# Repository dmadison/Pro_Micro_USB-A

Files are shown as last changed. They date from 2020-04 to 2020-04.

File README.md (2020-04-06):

Pro Micro w/ USB-A
=========

Pro Micro w/ USB-A

The Pro Micro is a micro controller with an ATMega32U4 IC on board.
The USB transceiver is inside the 32U4, adding USB connectivity on-board without external USB interfaces. 
This comes in both a 3.3V and 5V version. 

This repository was forked from [the original SparkFun Pro Micro repository](https://github.com/sparkfun/Pro_Micro). The board has been modified to use [a USB-A](https://en.wikipedia.org/wiki/USB_hardware#Connectors) connector.

For more information, see [the blog post on PartsNotIncluded.com](https://www.partsnotincluded.com/sparkfun-pro-micro-with-usb-a/).

Repository Contents
-------------------
* **/Documentation** - Data sheets (.pdf and .svg)
* **/Firmware** - Arduino example code used in the hookup guide
* **/Hardware** - All Eagle design files (.brd, .sch, .STL)
* **/Production** - Test bed files and production panel files

Documentation
--------------
* **[Hookup Guide](https://learn.sparkfun.com/tutorials/pro-micro--fio-v3-hookup-guide)** - Basic hookup guide for the Pro Micro.
* **[SparkFun Arduino Board Addon](https://github.com/sparkfun/Arduino_Boards/)** - Arduino board addon for Pro Micro.
* **[SparkFun Graphical Datasheets](https://github.com/sparkfun/Graphical_Datasheets)** - Graphical datasheets for various SparkFun products.
* **[USB-A Build Log](https://www.partsnotincluded.com/sparkfun-pro-micro-with-usb-a/)** - Build log for the USB-A version on PartsNotIncluded.com

Product Versions
----------------
* [DEV-12587](https://www.sparkfun.com/products/12587)- 3.3V/8MHz version
* [DEV-12640](https://www.sparkfun.com/products/12640)- 5V/16MHz version

License Information
-------------------
This product is _**open source**_! 

Please review the LICENSE.md file for license information. 

If you have any questions or concerns on licensing, please contact techsupport@sparkfun.com.

Distributed as-is; no warranty is given.

- Your friends at SparkFun.

_<COLLABORATION CREDIT>_

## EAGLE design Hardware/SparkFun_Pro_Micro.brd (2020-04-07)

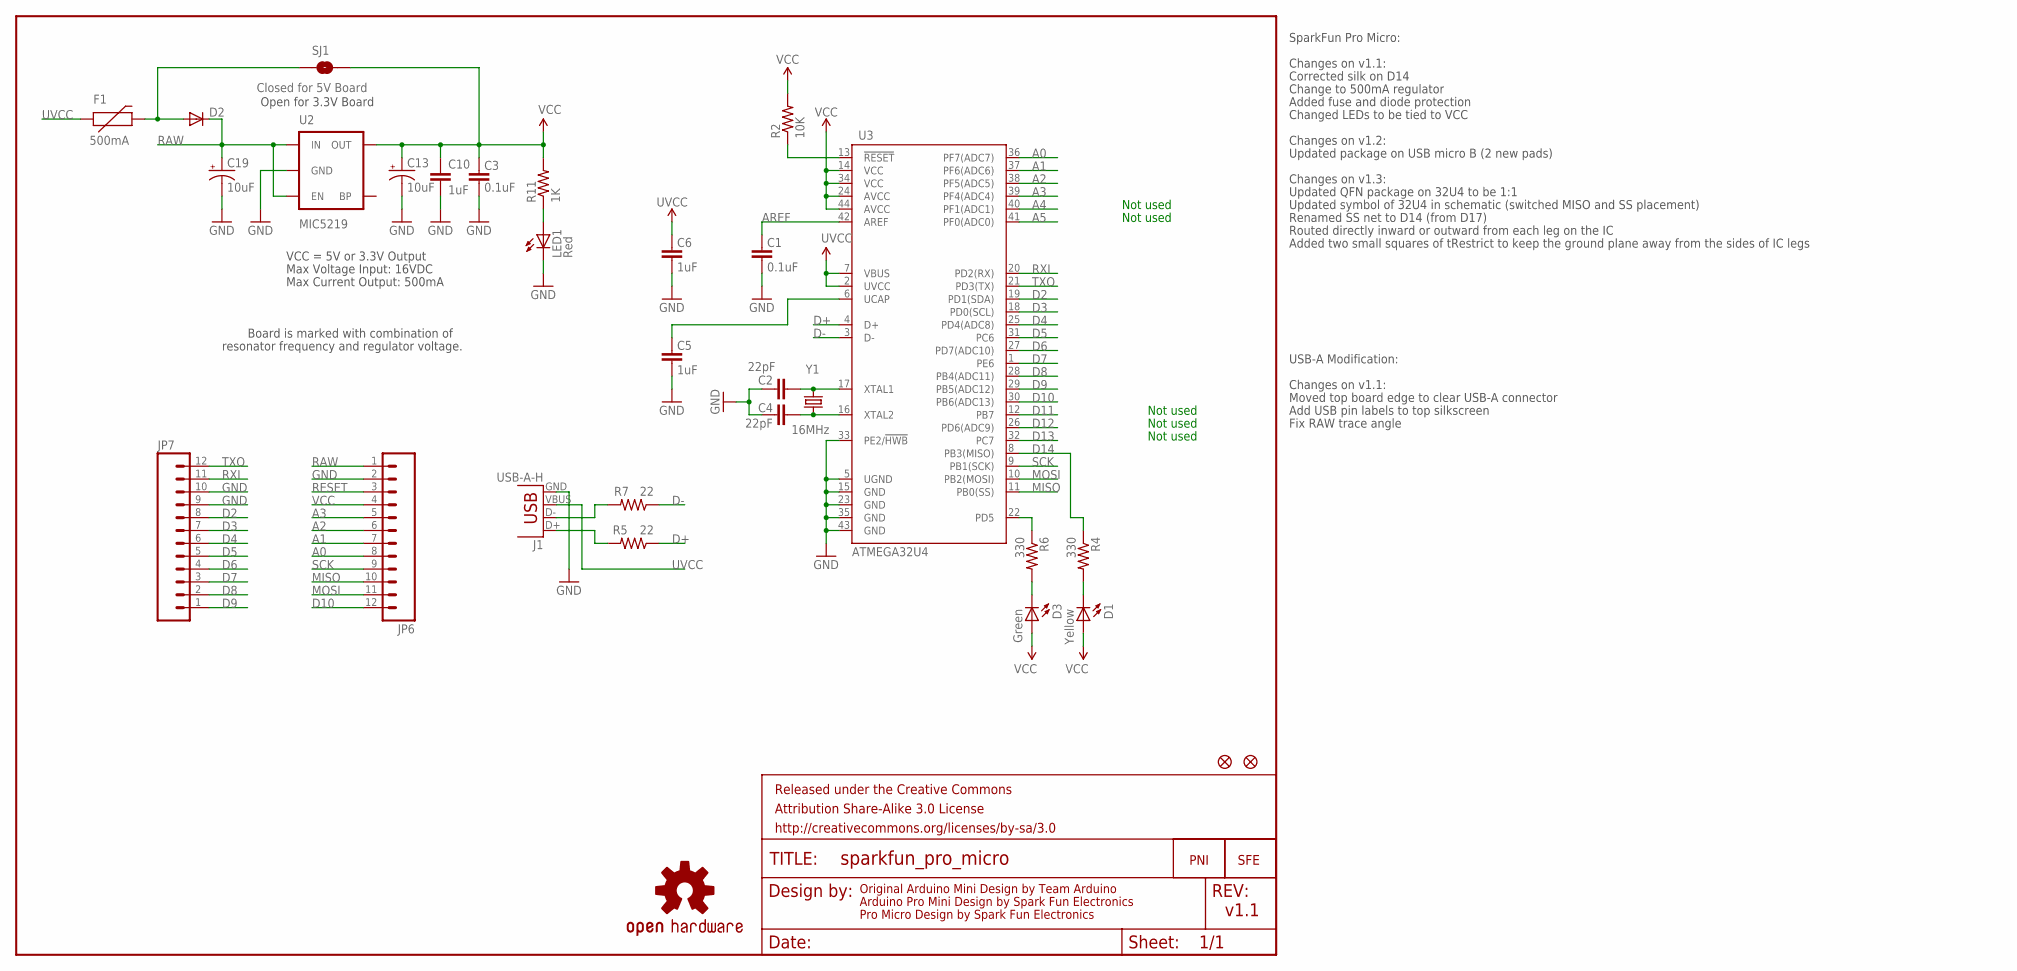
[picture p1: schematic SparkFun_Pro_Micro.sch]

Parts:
C1, C3: 0.1uF; 0603-CAP
C2, C4: 22pF; 0603-CAP
C5, C6, C10: 1uF; 0603-CAP
C13, C19: 10uF; EIA3216
D1: Yellow; LED-0603
D2: DIODESOD; SOD-323
D3: Green; LED-0603
F1: 500mA; PTC-1206
FRAME1: FRAME-LETTER; CREATIVE_COMMONS
J1: USB-A-H
JP1, JP2: FIDUCIALUFIDUCIAL; MICRO-FIDUCIAL
JP6, JP7: M12PTH; 1X12
LED1: Red; LED-0603
R2: 10K; 0603-RES
R4, R6: 330; 0603-RES
R5, R7: 22; 0603-RES
R11: 1K; 0603-RES
SJ1: Closed for 5V Board; SJ_2S
U2: MIC5219; SOT23-5
U3: ATMEGA32U4; QFN-44-NOPAD_1:1-OUTFAKES
U$1: LOGO-SFESK; SFE-LOGO-FLAME
U$2: PNI-PRO-MICRO-SPLIT-LOGO-TEXT
U$3: OSHW-LOGOS; OSHW-LOGO-S
Y1: 16MHz; CRYSTAL-SMD-5X3

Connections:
A0: JP6.8, U3.36 (PF7(ADC7))
A1: JP6.7, U3.37 (PF6(ADC6))
A2: JP6.6, U3.38 (PF5(ADC5))
A3: JP6.5, U3.39 (PF4(ADC4))
A4: U3.40 (PF1(ADC1))
A5: U3.41 (PF0(ADC0))
AREF: C1.2, U3.42 (AREF)
D2: JP7.8, U3.19 (PD1(SDA))
D3: JP7.7, U3.18 (PD0(SCL))
D4: JP7.6, U3.25 (PD4(ADC8))
D5: JP7.5, U3.31 (PC6)
D6: JP7.4, U3.27 (PD7(ADC10))
D7: JP7.3, U3.1 (PE6)
D8: JP7.2, U3.28 (PB4(ADC11))
D9: JP7.1, U3.29 (PB5(ADC12))
D10: JP6.12, U3.30 (PB6(ADC13))
D11: U3.12 (PB7)
D12: U3.26 (PD6(ADC9))
D13: U3.32 (PC7)
D14: R4.1, U3.8 (PB3(MISO))
D+: R5.1, U3.4 (D+)
D-: R7.1, U3.3 (D-)
GND: C1.1, C2.2, C3.1, C4.2, C5.1, C6.1, C10.2, C13.C (-), C19.C (-), J1.GND, JP6.2, JP7.9, JP7.10, LED1.C, U2.2 (GND), U3.5 (UGND), U3.15 (GND), U3.23 (GND), U3.33 (PE2/!HWB), U3.35 (GND), U3.43 (GND)
MISO: JP6.10, U3.11 (PB0(SS))
MOSI: JP6.11, U3.10 (PB2(MOSI))
unnamed: C4.1, U3.16 (XTAL2), Y1.1
unnamed: C2.1, U3.17 (XTAL1), Y1.3 (2)
unnamed: D2.2 (A), F1.2, SJ1.1
unnamed: C5.2, U3.6 (UCAP)
unnamed: D1.C, R4.2
unnamed: J1.D-, R7.2
unnamed: D3.C, R6.2
unnamed: J1.D+, R5.2
unnamed: LED1.A, R11.1
RAW: C19.A (+), D2.1 (C), JP6.1, U2.1 (IN), U2.3 (EN)
RESET: JP6.3, R2.1, U3.13 (!RESET)
RXI: JP7.11, U3.20 (PD2(RX))
SCK: JP6.9, U3.9 (PB1(SCK))
TXLED: R6.1, U3.22 (PD5)
TXO: JP7.12, U3.21 (PD3(TX))
UVCC: C6.2, F1.1, J1.VBUS, U3.2 (UVCC), U3.7 (VBUS)
VCC: C3.2, C10.1, C13.A (+), D1.A, D3.A, JP6.4, R2.2, R11.2, SJ1.2, U2.5 (OUT), U3.14 (VCC), U3.24 (AVCC), U3.34 (VCC), U3.44 (AVCC)

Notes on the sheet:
Original Arduino Mini Design by Team Arduino
Arduino Pro Mini Design by Spark Fun Electronics
Max Voltage Input: 16VDC
Max Current Output: 500mA
Board is marked with combination of
resonator frequency and regulator voltage.
VCC = 5V or 3.3V Output
Not used
Pro Micro Design by Spark Fun Electronics
Changes on v1.1:
Corrected silk on D14
Change to 500mA regulator
Open for 3.3V Board
Added fuse and diode protection
Changed LEDs to be tied to VCC
Changes on v1.2:
Updated package on USB micro B (2 new pads)
Changes on v1.3:
Updated QFN package on 32U4 to be 1:1
Updated symbol of 32U4 in schematic (switched MISO and SS placement)
Renamed SS net to D14 (from D17)
Routed directly inward or outward from each leg on the IC
Added two small squares of tRestrict to keep the ground plane away from the sides of IC legs
v1.1
SparkFun Pro Micro:
Moved top board edge to clear USB-A connector
Add USB pin labels to top silkscreen
Fix RAW trace angle
USB-A Modification:

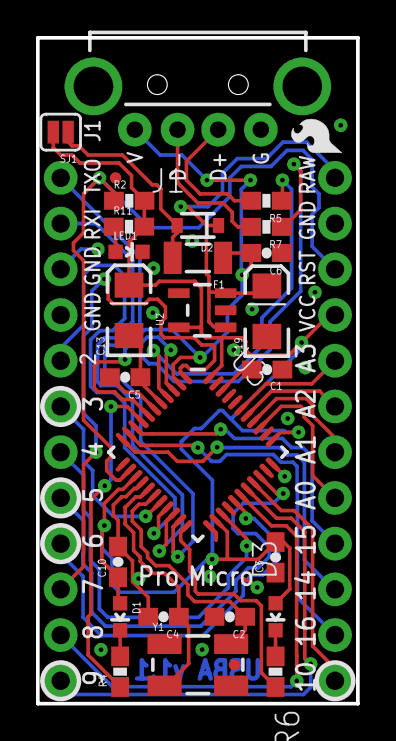
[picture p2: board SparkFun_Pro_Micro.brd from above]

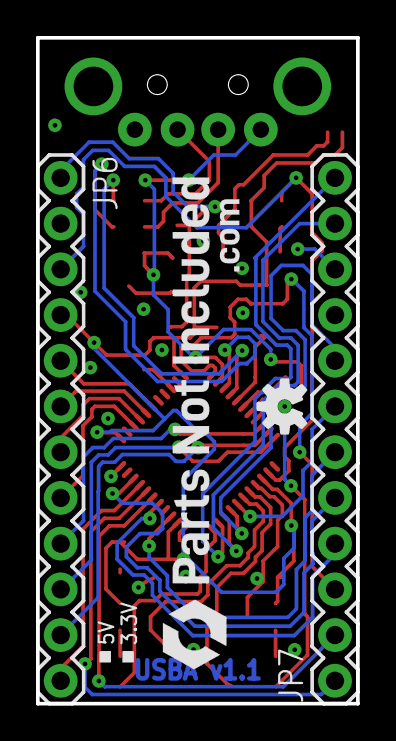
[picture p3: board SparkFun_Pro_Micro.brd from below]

Board: 2 copper layers, 17.8 x 37.0 mm, 33 parts (4 on the bottom side), 37 nets.

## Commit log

2020-02-23 Swap USB-B micro with USB-A male connector
    [SparkFun_Pro_Micro.brd, SparkFun_Pro_Micro.sch]
2020-02-23 Remove SparkFun logo on bottom silkscreen
    This is cleverly hiding in the corner of the schematic as part of the title frame (look for "SFE" on the right).
    [SparkFun_Pro_Micro.brd, SparkFun_Pro_Micro.sch]
2020-02-23 Add PartsNotIncluded logo to bottom silkscreen
    [SparkFun_Pro_Micro.brd, SparkFun_Pro_Micro.sch]
2020-02-23 Update bottom copper version number for USBA
    "v1"!
    [SparkFun_Pro_Micro.brd]
2020-04-04 Move top board edge inwards to clear USB-A jack
    On version 1.0 the jack doesn't *quite* fit without a little sanding. It turns out that the footprint's silkscreen marker for the top of the board clearance area is off by 0.1 mm (3 mm in the footprint, 2.9 mm in the datasheet), and my board edge followed the grid so it was 0.05 mm past even that. This commit pulls the board edge back to properly accomodate the connector.
    Now according to the datasheet the lower edge of the connector is 18.8 mm from the tip, with the mounting tabs 2 mm long. Because the origin of the footprint is the center of these mounting tabs, that makes the origin 17.8 mm offset from the tip. The end of the cutout area is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
    [SparkFun_Pro_Micro.brd]
2020-04-04 Add USB pin labels to top silkscreen
    [SparkFun_Pro_Micro.brd]
2020-04-04 Increase clearance around USB-A trace vias
    [SparkFun_Pro_Micro.brd]
2020-04-04 Fix RAW trace angle
    This was not 45 degrees!
    [SparkFun_Pro_Micro.brd]
2020-04-04 Tweak USB pin silkscreen labels to use "D" prefix
    More clearly distinguishing the data pins from the power and ground (which could also conceivably be confused with '+' and '-')
    [SparkFun_Pro_Micro.brd]
2020-04-04 USBA Version 1.1 on bottom copper
    [SparkFun_Pro_Micro.brd]
2020-04-06 Update version number in schematic (v1.1)
    Using the USB-A version number instead of the Pro Micro number, for internal consistency
    [SparkFun_Pro_Micro.sch]
2020-04-06 Add USB-A version changes to schematic
    [SparkFun_Pro_Micro.sch]
2020-04-07 Center version number on bottom copper
    [SparkFun_Pro_Micro.brd]

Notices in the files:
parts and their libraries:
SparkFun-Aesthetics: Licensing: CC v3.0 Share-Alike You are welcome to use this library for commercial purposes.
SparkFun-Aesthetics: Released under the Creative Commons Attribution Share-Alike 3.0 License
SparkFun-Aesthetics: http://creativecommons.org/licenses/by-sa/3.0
